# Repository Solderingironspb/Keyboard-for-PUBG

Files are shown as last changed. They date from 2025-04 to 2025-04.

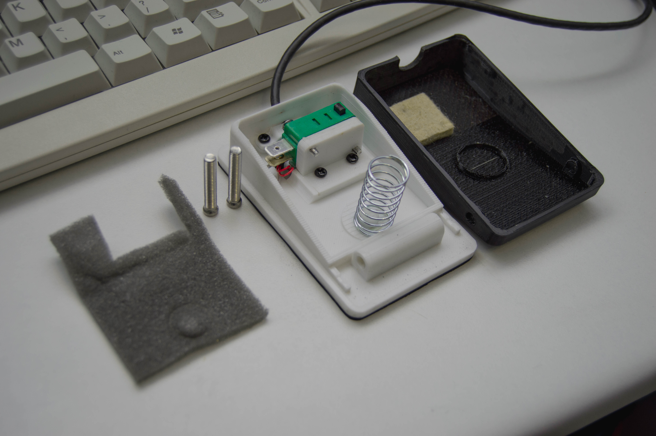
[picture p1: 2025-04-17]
images/photo (4).jpg

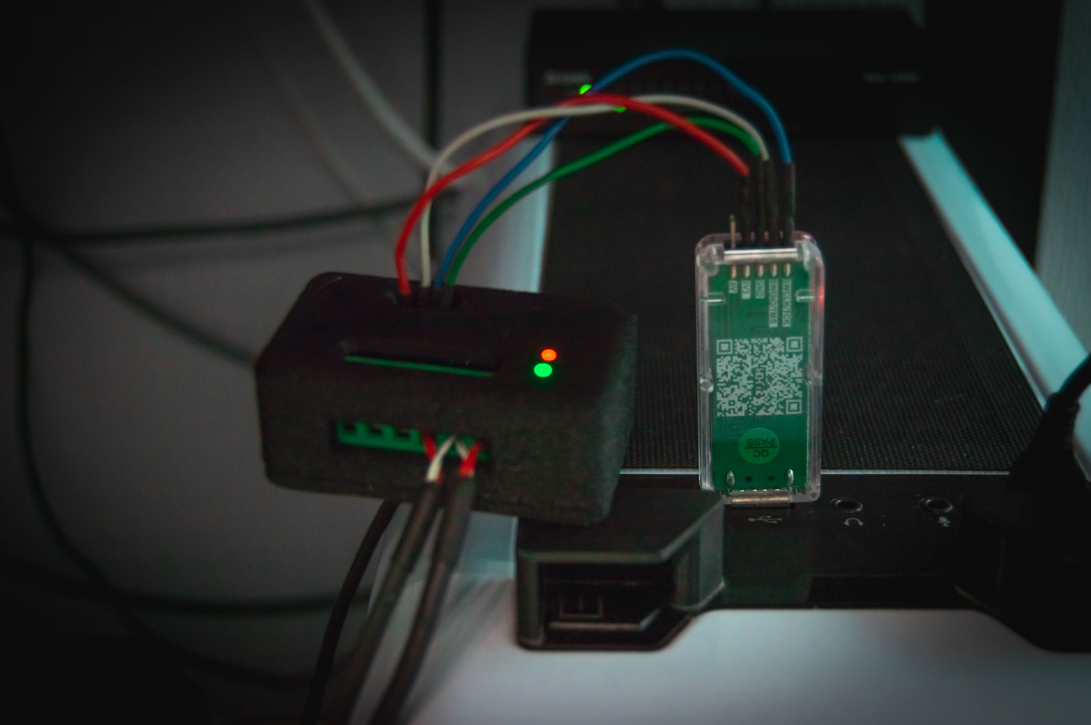
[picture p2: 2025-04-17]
images/photo (3).jpg

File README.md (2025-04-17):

# Keyboard-for-PUBG (4 кнопочный контроллер для игры PUBG)
*Проект 4 кнопочного контроллера на RISC-V микроконтроллере CH32V203F6P6 для игры PUBG. При желании можно адаптировать под что угодно...*

*В основном мне нужны только 2 доп. педали, чтоб удобно было играть - это быстрый присед и рация. Вот ногами и делаю жмяк-жмяк :D*

*Каким бы бесполезным не казался проект, мол игрульки, детские забавы - а Вы попробуйте поднять USB на данных микроконтроллерах, напишите код. Создайте печатную плату под это все. Разработайте 3D модели устройства и педалей. Это же куча времени и полезного опыта :)*

## Особенности проекта:
* Печатная плата разработана в KiCad 8
* Есть файлы *.stl для слайсера. Все напечатано на 3D принтере.
* В папке firmware  хранятся готовые файлы прошивки CH32V203F6P6 в форматах *.hex и *.bin
* Проект написан в VSCode. Используется toolchain от MRStudio RISC-V_Embedded_GCC12. Makefile присутствует.
* Кнопка для рации: https://www.chipdip.ru/product/pbs-24b-4
* Концевой выключатель для педальки: https://www.chipdip.ru/product/msw-01
* Пружина в педальку: Толщина проволоки 1 мм, диаметр пружины 15 мм, высота пружины 32 мм.
* Винты в педальке: М5 30мм.
* Войлок в педальку для мягкого клика: 4.5 мм (из валенка) :D
* Клей, которым приклеивал войлок и резиновую подошву на педали: 88 Luxe. Рекомендую. Очень хороший клей.
   










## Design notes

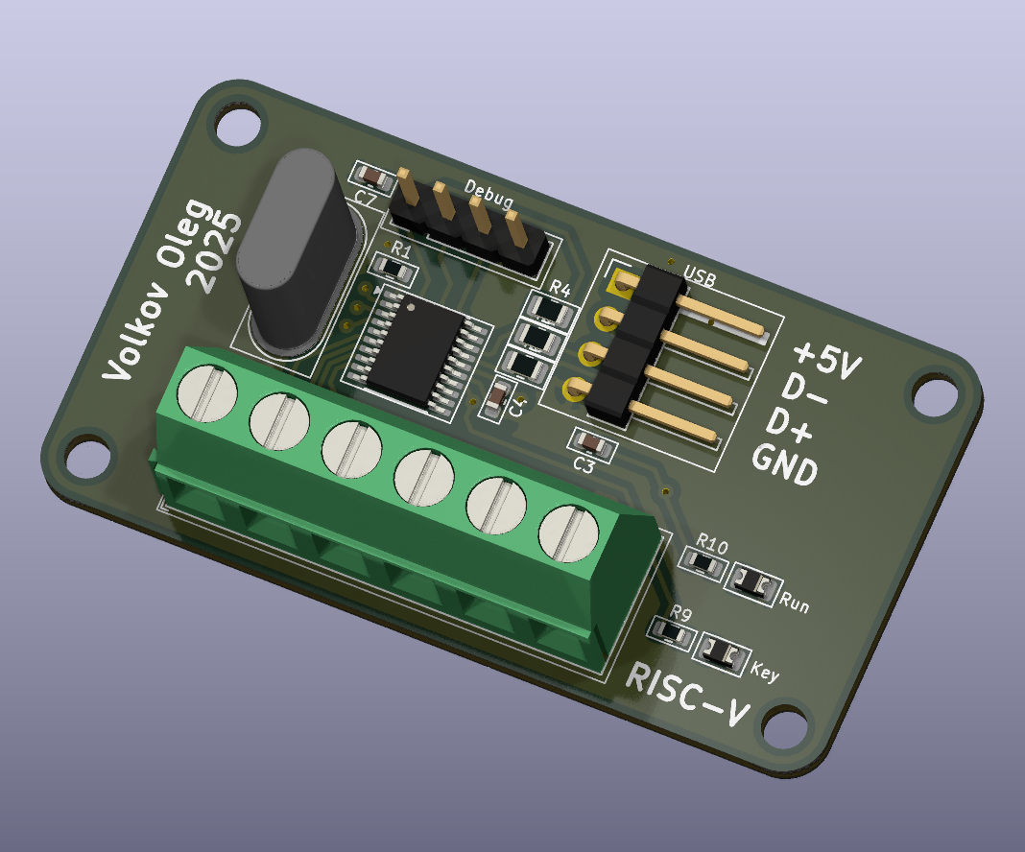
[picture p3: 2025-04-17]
images/PCB.png

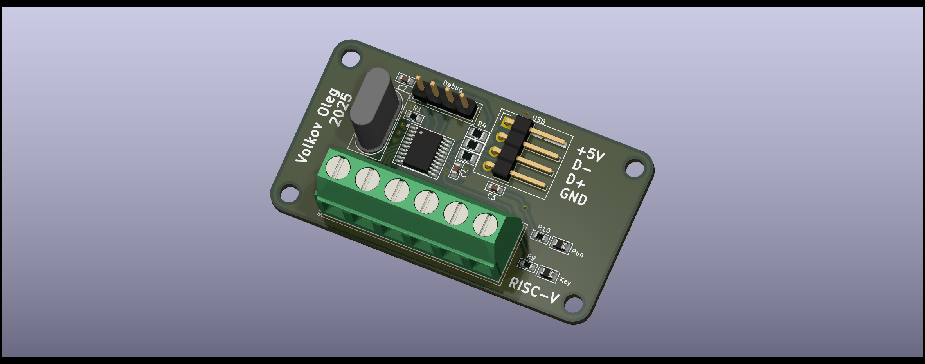
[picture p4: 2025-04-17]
PCB/PUBG_KEY/PUBG_KEY.png

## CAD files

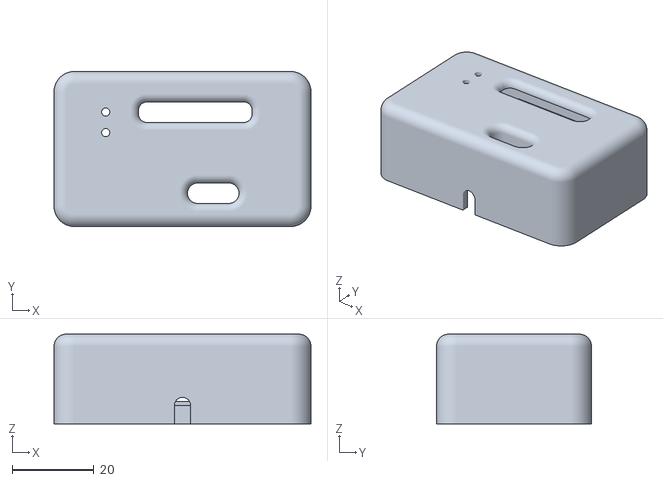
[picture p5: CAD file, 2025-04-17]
3D/PUBG/keyboard.stl
63.0 x 38.0 x 22.0

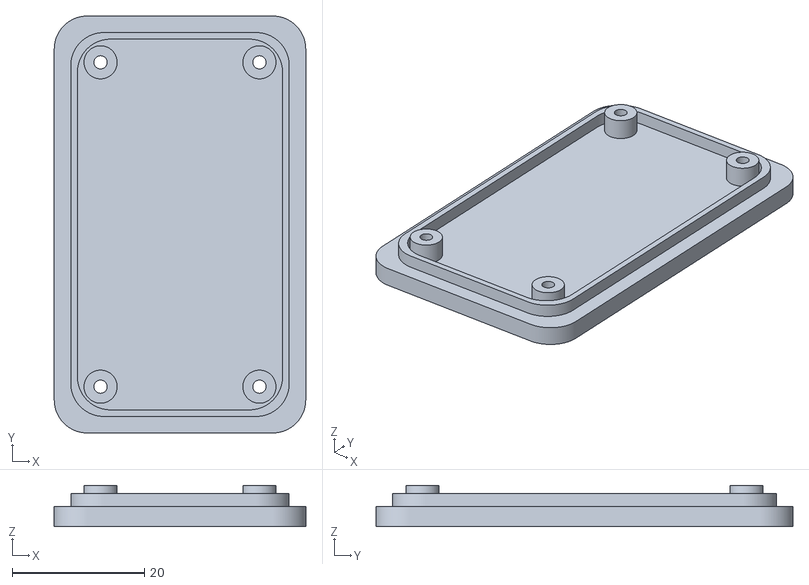
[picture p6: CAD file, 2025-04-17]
3D/PUBG/keyboard_back.stl
38.0 x 63.0 x 6.20

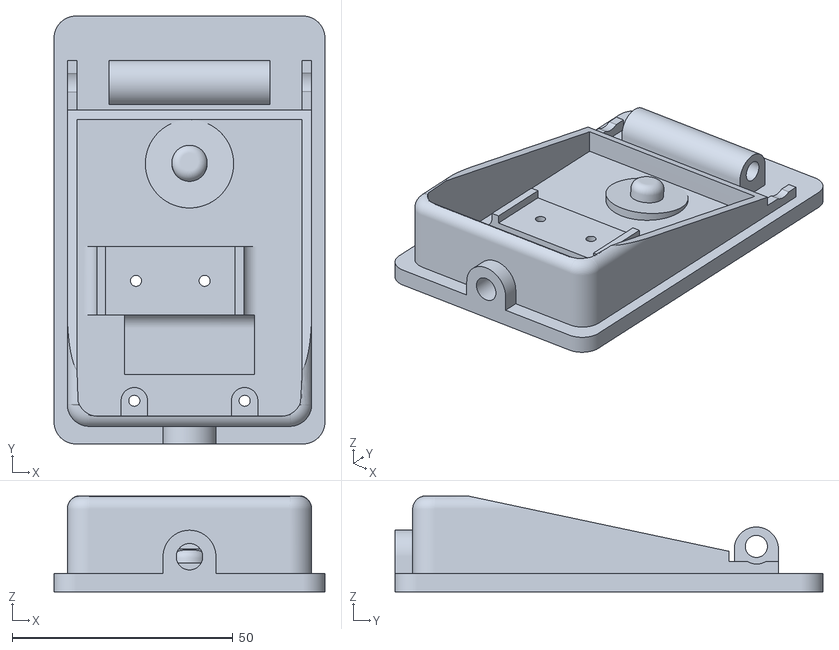
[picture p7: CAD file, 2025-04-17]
3D/PUBG/Foot_pedal_back.stl
61.4 x 97.0 x 21.7

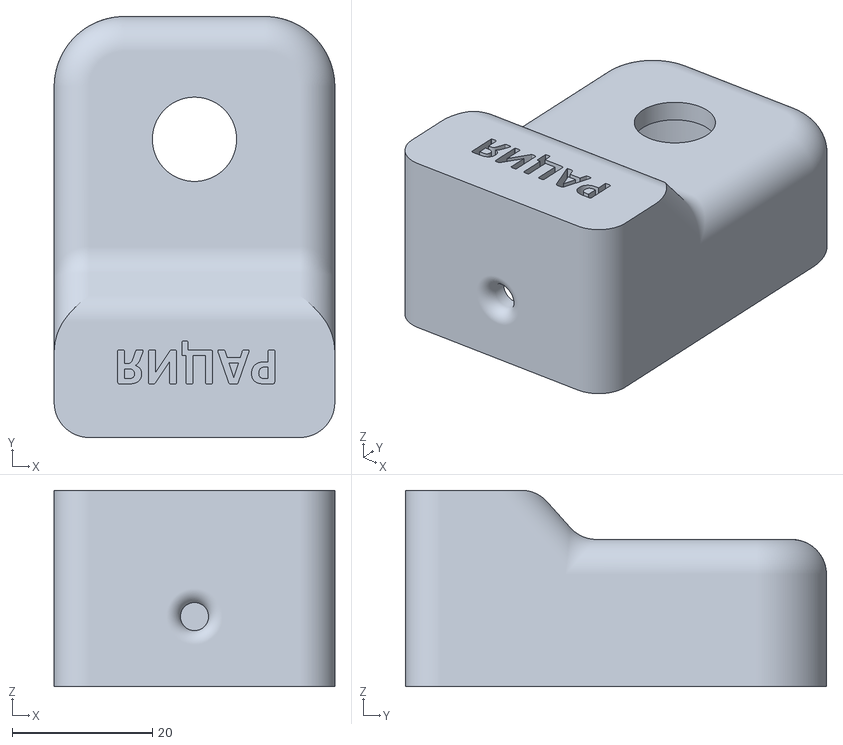
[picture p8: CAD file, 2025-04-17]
3D/PUBG/PTT.stl
40.0 x 60.0 x 28.0

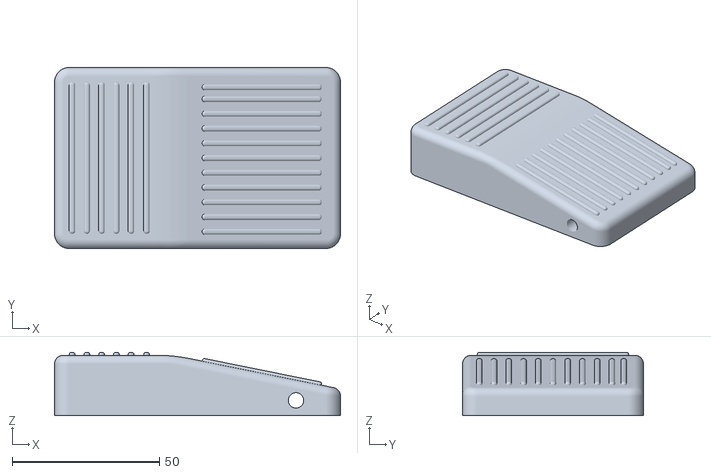
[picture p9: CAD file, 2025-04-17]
3D/PUBG/Foot_pedal_top.stl
97.0 x 61.4 x 21.5

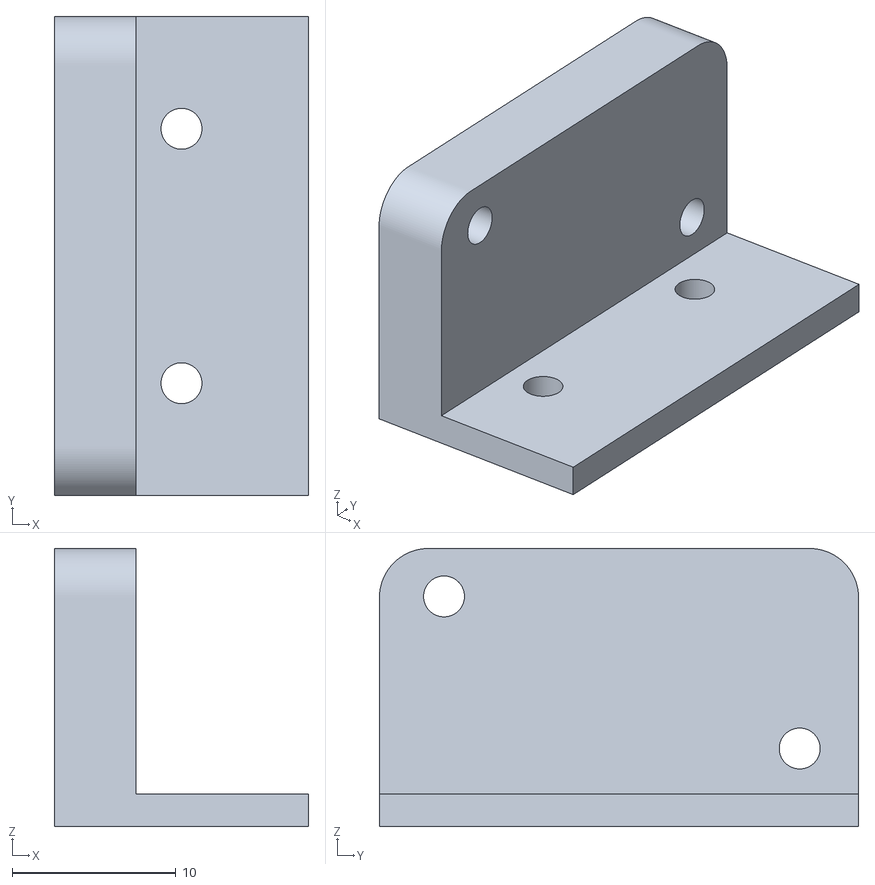
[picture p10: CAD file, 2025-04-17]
3D/PUBG/Foot_pedal_switch_platform.stl
15.6 x 29.3 x 17.0

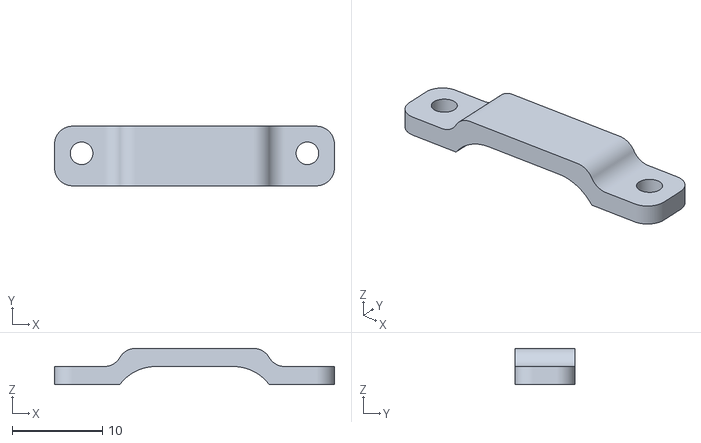
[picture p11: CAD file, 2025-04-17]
3D/PUBG/Foot_pedal_skoba.stl
31.0 x 6.60 x 4.00

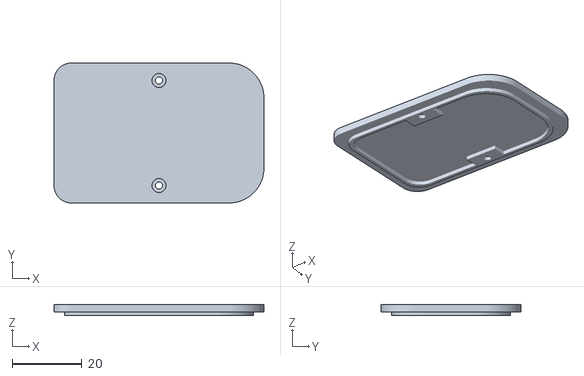
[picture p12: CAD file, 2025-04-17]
3D/PUBG/PTT_back.stl
60.0 x 40.0 x 3.00

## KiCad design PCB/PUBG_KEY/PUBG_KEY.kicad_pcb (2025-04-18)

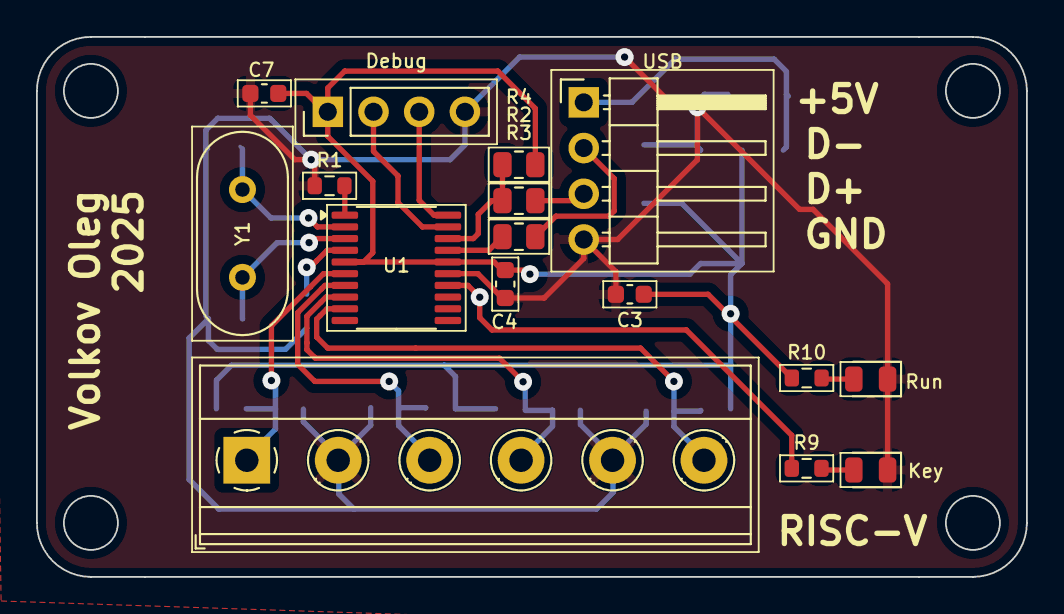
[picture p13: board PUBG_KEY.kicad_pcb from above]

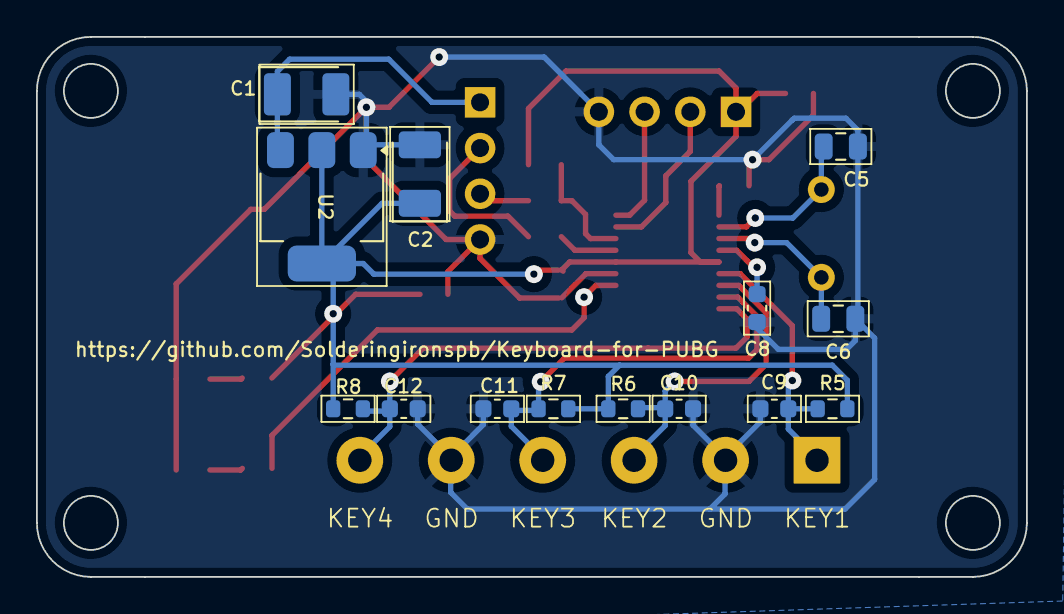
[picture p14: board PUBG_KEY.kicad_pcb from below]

Board: 2 copper layers, 55.0 x 30.0 mm, 30 parts (14 on the bottom side), 20 nets.

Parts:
C1, C2: 47uF; CP_EIA-3528-21_Kemet-B_Pad1.50x2.35mm_HandSolder
C3, C4, C7, C8, C9, C10, C11, C12: 100n; C_0603_1608Metric
C5, C6: 30pF; C_0805_2012Metric
Debug: Debug; PinHeader_1x04_P2.54mm_Vertical
J3: KEY_IN; TerminalBlock_Phoenix_MKDS-1,5-6-5.08_1x06_P5.08mm_Horizont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
Key: Key; D_0805_2012Metric
R1, R5, R6, R7, R8, R9, R10: 10k; R_0603_1608Metric
R2, R3: 20; R_0805_2012Metric
R4: 1.5k; R_0805_2012Metric
Run: Key; D_0805_2012Metric
U1: CH32V203F6P6; TSSOP-20_4.4x6.5mm_P0.65mm
U2: AMS1117-3.3; SOT-223-3_TabPin2
USB: USB; PinHeader_1x04_P2.54mm_Horizontal
Y1: 8MHz; Crystal_HC49-U_Vertical

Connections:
+5V: C1.1, U2.3 (VI), USB.1 (VBUS)
DM: R3.1, U1.17 (PA11/USB1DM)
DP: R2.1, R4.1, U1.18 (PA12/USB1DP)
GND: C1.2, C2.2, C3.2, C4.2, C5.1, C6.1, C7.2, C8.2, C9.2, C10.2, C11.2, C12.2, Debug.4, J3.2, J3.5, Key.1 (K), R1.1, Run.1 (K), U1.15 (VSS), U2.1 (GND), USB.4 (ID)
KEY1: C9.1, J3.1, R5.1, U1.6 (PA0/WKUP/ADC0)
KEY2: C10.1, J3.3, R6.1, U1.7 (PA1/ADC1)
KEY3: C11.1, J3.4, R7.1, U1.8 (PA2/ADC2)
KEY4: C12.1, J3.6, R8.1, U1.9 (PA3/ADC3)
LED: R9.1, U1.14 (PB1/ADC9)
unnamed: Key.2 (A), R9.2
unnamed: R10.2, Run.2 (A)
unnamed: R2.2, USB.3 (D+)
unnamed: R3.2, USB.2 (D-)
unnamed: R1.2, U1.1 (BOOT0/PB8)
unnamed: C8.1, U1.4 (NRST)
PD0: C5.2, U1.2 (OSC_IN/PD0), Y1.1
PD1: C6.2, U1.3 (OSC_OUT/PD1), Y1.2
SWCLK: Debug.3, U1.20 (PA14/SWCLK)
SWDIO: Debug.2, U1.19 (PA13/SWDIO)
VDD: C2.1, C3.1, C4.1, C7.1, Debug.1, R4.2, R5.2, R6.2, R7.2, R8.2, R10.1, U1.5 (VDDA), U1.16 (VDD), U2.2 (VO)

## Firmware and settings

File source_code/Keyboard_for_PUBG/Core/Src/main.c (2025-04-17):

/*
 * Пример Custom HID (Keyboard) на CH32V203F6P6
 * В файле usb_desc.h можно найти основные определения:
 * - USBD_VID - VID устройства
 * - USBD_PID - PID устройства
 * - USBD_LANGID_STRING - языковой идентификатор
 * - USBD_SIZE_REPORT_DESC - размер репорт десктриптора (данный дестриптор
 * описывает геймпад)
 * - CUSTOM_HID_BINTERVAL - интервал, с которым геймпад будет опрашиваться (в
 * мс) В файле usb_desc.c можно найти основные настройки устройства:
 * - const uint8_t USBD_DeviceDescriptor[USBD_SIZE_DEVICE_DESC] - USB Device
 * Descriptors
 * - const uint8_t USBD_ConfigDescriptor[USBD_SIZE_CONFIG_DESC] - USB
 * Configration Descriptors
 * - const uint8_t USBD_HidRepDesc[USBD_SIZE_REPORT_DESC] - HID Report
 * Descriptor(он описывает наш геймпад: сколько кнопок, осей, и т.д.)
 * - uint8_t StringVendor[64] - Кастомный iManufacturer
 * - uint8_t StringProduct[64] - Кастомный iProduct
 * - const uint8_t USBD_StringSerial[USBD_SIZE_STRING_SERIAL] - Серийный номер
 * устройства (см. стр. 53 Keyboard/Keypad
 * table)https://www.usb.org/sites/default/files/documents/hut1_12v2.pdf
 *
 */
#include "main.h"
#include "hw_config.h"
#include "stdio.h"
#include "usb_desc.h"
#include "usb_lib.h"
#include "usb_prop.h"
#include "usb_pwr.h"
#include "usbd_compatibility_hid.h"

#define LED_ON  GPIOB->BSHR = GPIO_BSHR_BS1
#define LED_OFF GPIOB->BSHR = GPIO_BSHR_BR1
bool flag_led = false;
uint8_t Reset_cnt = 4;

extern uint8_t USBD_ENDPx_DataUp(uint8_t endp, uint8_t *pbuf, uint16_t len);

/*Структура нашего геймпада. В точности повторяет HID Report Descriptor*/
typedef struct __attribute__((packed)) {
    uint8_t Modifier_keys;
    uint8_t Reserved;
    uint8_t Keycode_1;
    uint8_t Keycode_2;
    uint8_t Keycode_3;
    uint8_t Keycode_4;
    uint8_t Keycode_5;
    uint8_t Keycode_6;

} USB_Custom_HID_Keyboard;

USB_Custom_HID_Keyboard Keyboard_data;

int main(void) {
    RVMSIS_Debug_init();              // Настройка дебага
    RVMSIS_RCC_SystemClock_144MHz();  // Настройка системной частоты
    RVMSIS_SysTick_Timer_init();      // Настройка системного таймера

    // Настройка GPIO
    RVMSIS_GPIO_init(GPIOB, 1, GPIO_GENERAL_PURPOSE_OUTPUT, GPIO_OUTPUT_PUSH_PULL, GPIO_SPEED_50_MHZ);  // LED
    RVMSIS_GPIO_init(GPIOA, 0, GPIO_INPUT, GPIO_INPUT_FLOATING, GPIO_SPEED_RESERVED);                   // KEY1
    RVMSIS_GPIO_init(GPIOA, 1, GPIO_INPUT, GPIO_INPUT_FLOATING, GPIO_SPEED_RESERVED);                   // KEY2
    RVMSIS_GPIO_init(GPIOA, 2, GPIO_INPUT, GPIO_INPUT_FLOATING, GPIO_SPEED_RESERVED);                   // KEY3
    RVMSIS_GPIO_init(GPIOA, 3, GPIO_INPUT, GPIO_INPUT_FLOATING, GPIO_SPEED_RESERVED);                   // KEY4

    Set_USBConfig();
    USB_Init();
    USB_Interrupts_Config();

    /*Инициализация структуры клавиатуры*/
    Keyboard_data.Modifier_keys = 0;
    Keyboard_data.Reserved = 0;
    Keyboard_data.Keycode_1 = 0x0;
    Keyboard_data.Keycode_2 = 0x0;
    Keyboard_data.Keycode_3 = 0x0;
    Keyboard_data.Keycode_4 = 0x0;
    Keyboard_data.Keycode_5 = 0x0;
    Keyboard_data.Keycode_6 = 0x0;

    while (1) {
        if (bDeviceState == CONFIGURED) {
            /*Keycode_1*/
            if (!READ_BIT(GPIOA->INDR, GPIO_INDR_IDR3)) {
                Keyboard_data.Modifier_keys = 0;
                Keyboard_data.Keycode_1 = 0x6;  // C
            } else {
                Keyboard_data.Modifier_keys = 0;
                Keyboard_data.Keycode_1 = 0;
            }

            /*Keycode_2*/
            if (!READ_BIT(GPIOA->INDR, GPIO_INDR_IDR2)) {
                Keyboard_data.Modifier_keys = 0;
                Keyboard_data.Keycode_2 = 0x17;  // T
            } else {
                Keyboard_data.Modifier_keys = 0;
                Keyboard_data.Keycode_2 = 0;
            }

            /*Keycode_3*/
            if (!READ_BIT(GPIOA->INDR, GPIO_INDR_IDR1)) {
                Keyboard_data.Modifier_keys = 0;
                Keyboard_data.Keycode_3 = 0x0C;  // I
            } else {
                Keyboard_data.Modifier_keys = 0;
                Keyboard_data.Keycode_3 = 0;
            }

            /*Keycode_4*/
            if (!READ_BIT(GPIOA->INDR, GPIO_INDR_IDR0)) {
                Keyboard_data.Modifier_keys = 0;
                Keyboard_data.Keycode_4 = 0x13;  // P
            } else {
                Keyboard_data.Modifier_keys = 0;
                Keyboard_data.Keycode_4 = 0;
            }

            /*Моргнем при активности*/
            uint8_t State = (uint8_t)(GPIOA->INDR);
            if (State < 0xF) {
                LED_ON;
            } else {
                Keyboard_data.Modifier_keys = 0;
                Keyboard_data.Reserved = 0;
                Keyboard_data.Keycode_1 = 0x0;
                Keyboard_data.Keycode_2 = 0x0;
                Keyboard_data.Keycode_3 = 0x0;
                Keyboard_data.Keycode_4 = 0x0;
                Keyboard_data.Keycode_5 = 0x0;
                Keyboard_data.Keycode_6 = 0x0;
                LED_OFF;
            }
            // Отправим в репорт сформированный буфер
            USBD_ENDPx_DataUp(ENDP2, (uint8_t *)&Keyboard_data, sizeof(Keyboard_data));
        } else {
            LED_ON;
            Delay_ms(500);
            LED_OFF;
            Delay_ms(500);

            if (Reset_cnt) {
                Reset_cnt--;
            } else {
                NVIC_SystemReset(); //Если ПК уже 5 секунд не видит устройство - перезагрузим МК(Костыль, т.к. после перезагрузки ПК - устройство видится в диспетчере устройств, но ничего не отправляет. Каждый раз передергивать USB надоело. А как исправить этот косяк - я так и не разобрался...)
            }
        }
    }
}

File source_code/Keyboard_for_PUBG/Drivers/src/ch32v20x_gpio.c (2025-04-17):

/********************************** (C) COPYRIGHT  *******************************
 * File Name          : ch32v20x_gpio.c
 * Author             : WCH
 * Version            : V1.0.0
 * Date               : 2024/05/06
 * Description        : This file provides all the GPIO firmware functions.
 *********************************************************************************
 * Copyright (c) 2021 Nanjing Qinheng Microelectronics Co., Ltd.
 * Attention: This software (modified or not) and binary are used for 
 * microcontroller manufactured by Nanjing Qinheng Microelectronics.
 *******************************************************************************/
#include "ch32v20x_rcc.h"
#include "ch32v20x_gpio.h"

#include "ch32v20x_rcc.h"
#include "ch32v20x_rcc.h"

/* MASK */
#define ECR_PORTPINCONFIG_MASK    ((uint16_t)0xFF80)
#define LSB_MASK                  ((uint16_t)0xFFFF)
#define DBGAFR_POSITION_MASK      ((uint32_t)0x000F0000)
#define DBGAFR_SWJCFG_MASK        ((uint32_t)0xF0FFFFFF)
#define DBGAFR_LOCATION_MASK      ((uint32_t)0x00200000)
#define DBGAFR_NUMBITS_MASK       ((uint32_t)0x00100000)

#if defined (CH32V20x_D6)
uint8_t MCU_Version = 0;
#endif

/*********************************************************************
 * @fn      GPIO_DeInit
 *
 * @brief   Deinitializes the GPIOx peripheral registers to their default
 *        reset values.
 *
 * @param   GPIOx - where x can be (A..G) to select the GPIO peripheral.
 *
 * @return  none
 */
void GPIO_DeInit(GPIO_TypeDef *GPIOx)
{
    if(GPIOx == GPIOA)
    {
        RCC_APB2PeriphResetCmd(RCC_APB2Periph_GPIOA, ENABLE);
        RCC_APB2PeriphResetCmd(RCC_APB2Periph_GPIOA, DISABLE);
    }
    else if(GPIOx == GPIOB)
    {
        RCC_APB2PeriphResetCmd(RCC_APB2Periph_GPIOB, ENABLE);
        RCC_APB2PeriphResetCmd(RCC_APB2Periph_GPIOB, DISABLE);
    }
    else if(GPIOx == GPIOC)
    {
        RCC_APB2PeriphResetCmd(RCC_APB2Periph_GPIOC, ENABLE);
        RCC_APB2PeriphResetCmd(RCC_APB2Periph_GPIOC, DISABLE);
    }
    else if(GPIOx == GPIOD)
    {
        RCC_APB2PeriphResetCmd(RCC_APB2Periph_GPIOD, ENABLE);
        RCC_APB2PeriphResetCmd(RCC_APB2Periph_GPIOD, DISABLE);
    }
    else if(GPIOx == GPIOE)
    {
        RCC_APB2PeriphResetCmd(RCC_APB2Periph_GPIOE, ENABLE);
        RCC_APB2PeriphResetCmd(RCC_APB2Periph_GPIOE, DISABLE);
    }
}

/*********************************************************************
 * @fn      GPIO_AFIODeInit
 *
 * @brief   Deinitializes the Alternate Functions (remap, event control
 *        and EXTI configuration) registers to their default reset values.
 *
 * @return  none
 */
void GPIO_AFIODeInit(void)
{
    RCC_APB2PeriphResetCmd(RCC_APB2Periph_AFIO, ENABLE);
    RCC_APB2PeriphResetCmd(RCC_APB2Periph_AFIO, DISABLE);
}

/*********************************************************************
 * @fn      GPIO_Init
 *
 * @brief   GPIOx - where x can be (A..G) to select the GPIO peripheral.
 *
 * @param   GPIO_InitStruct - pointer to a GPIO_InitTypeDef structure that
 *        contains the configuration information for the specified GPIO peripheral.
 *
 * @return  none
 */
void GPIO_Init(GPIO_TypeDef *GPIOx, GPIO_InitTypeDef *GPIO_InitStruct)
{
    uint32_t currentmode = 0x00, currentpin = 0x00, pinpos = 0x00, pos = 0x00;
    uint32_t tmpreg = 0x00, pinmask = 0x00;

    currentmode = ((uint32_t)GPIO_InitStruct->GPIO_Mode) & ((uint32_t)0x0F);

    if((((uint32_t)GPIO_InitStruct->GPIO_Mode) & ((uint32_t)0x10)) != 0x00)
    {
        currentmode |= (uint32_t)GPIO_InitStruct->GPIO_Speed;
    }
#if defined (CH32V20x_D6)
    if(((*(uint32_t *) 0x40022030) & 0x0F000000) == 0)
    {
        MCU_Version = 1;
    }

    if((GPIOx == GPIOC) && MCU_Version){
        GPIO_InitStruct->GPIO_Pin = GPIO_InitStruct->GPIO_Pin >> 13;
    }
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
